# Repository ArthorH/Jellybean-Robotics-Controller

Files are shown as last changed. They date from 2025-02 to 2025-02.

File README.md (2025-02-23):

# ESP8266 Multipurpose robotics controller 
 made from certified jellybean components!
 
obraz

obraz

## Project Status: **Finished**  
**Design** ✅ — **Fabrication** ✅ — **Assembly** ✅ — **Bringup** ✅ — **Testing** ✅  

## Key technologies:
&nbsp;&nbsp;&nbsp;&nbsp; &nbsp;&nbsp;&nbsp;&nbsp; &nbsp;&nbsp;&nbsp;&nbsp; &nbsp;&nbsp;&nbsp;&nbsp;

## Features
- Jelly Bean Components
- Universal footprints
- All usefull gpios has been broken out to connectors
- Additional I2C expander
- Battery voltage measurement
- Integrated easy to solder BMS module footprint (HW341)

Boards in different configuration
## Jelly Bean components 
Board designed to allow manufacture of simple but capable wifi enabled robotics controller from most common avaliable components.



## Universal footprints
Board is designed to handle multiple packages of same components:

 

## Integrated BMS controller 
Integrated easy to solder BMS module footprint (HW341)



## Notice: BMS it needs to be bodged in order to work
This model of bms would not be used in future designs



# Use cases
## PCB mounted on simple mobile robot

## PCB used in a pneumatic controller during the robotic arena.
obraz

## License

MIT

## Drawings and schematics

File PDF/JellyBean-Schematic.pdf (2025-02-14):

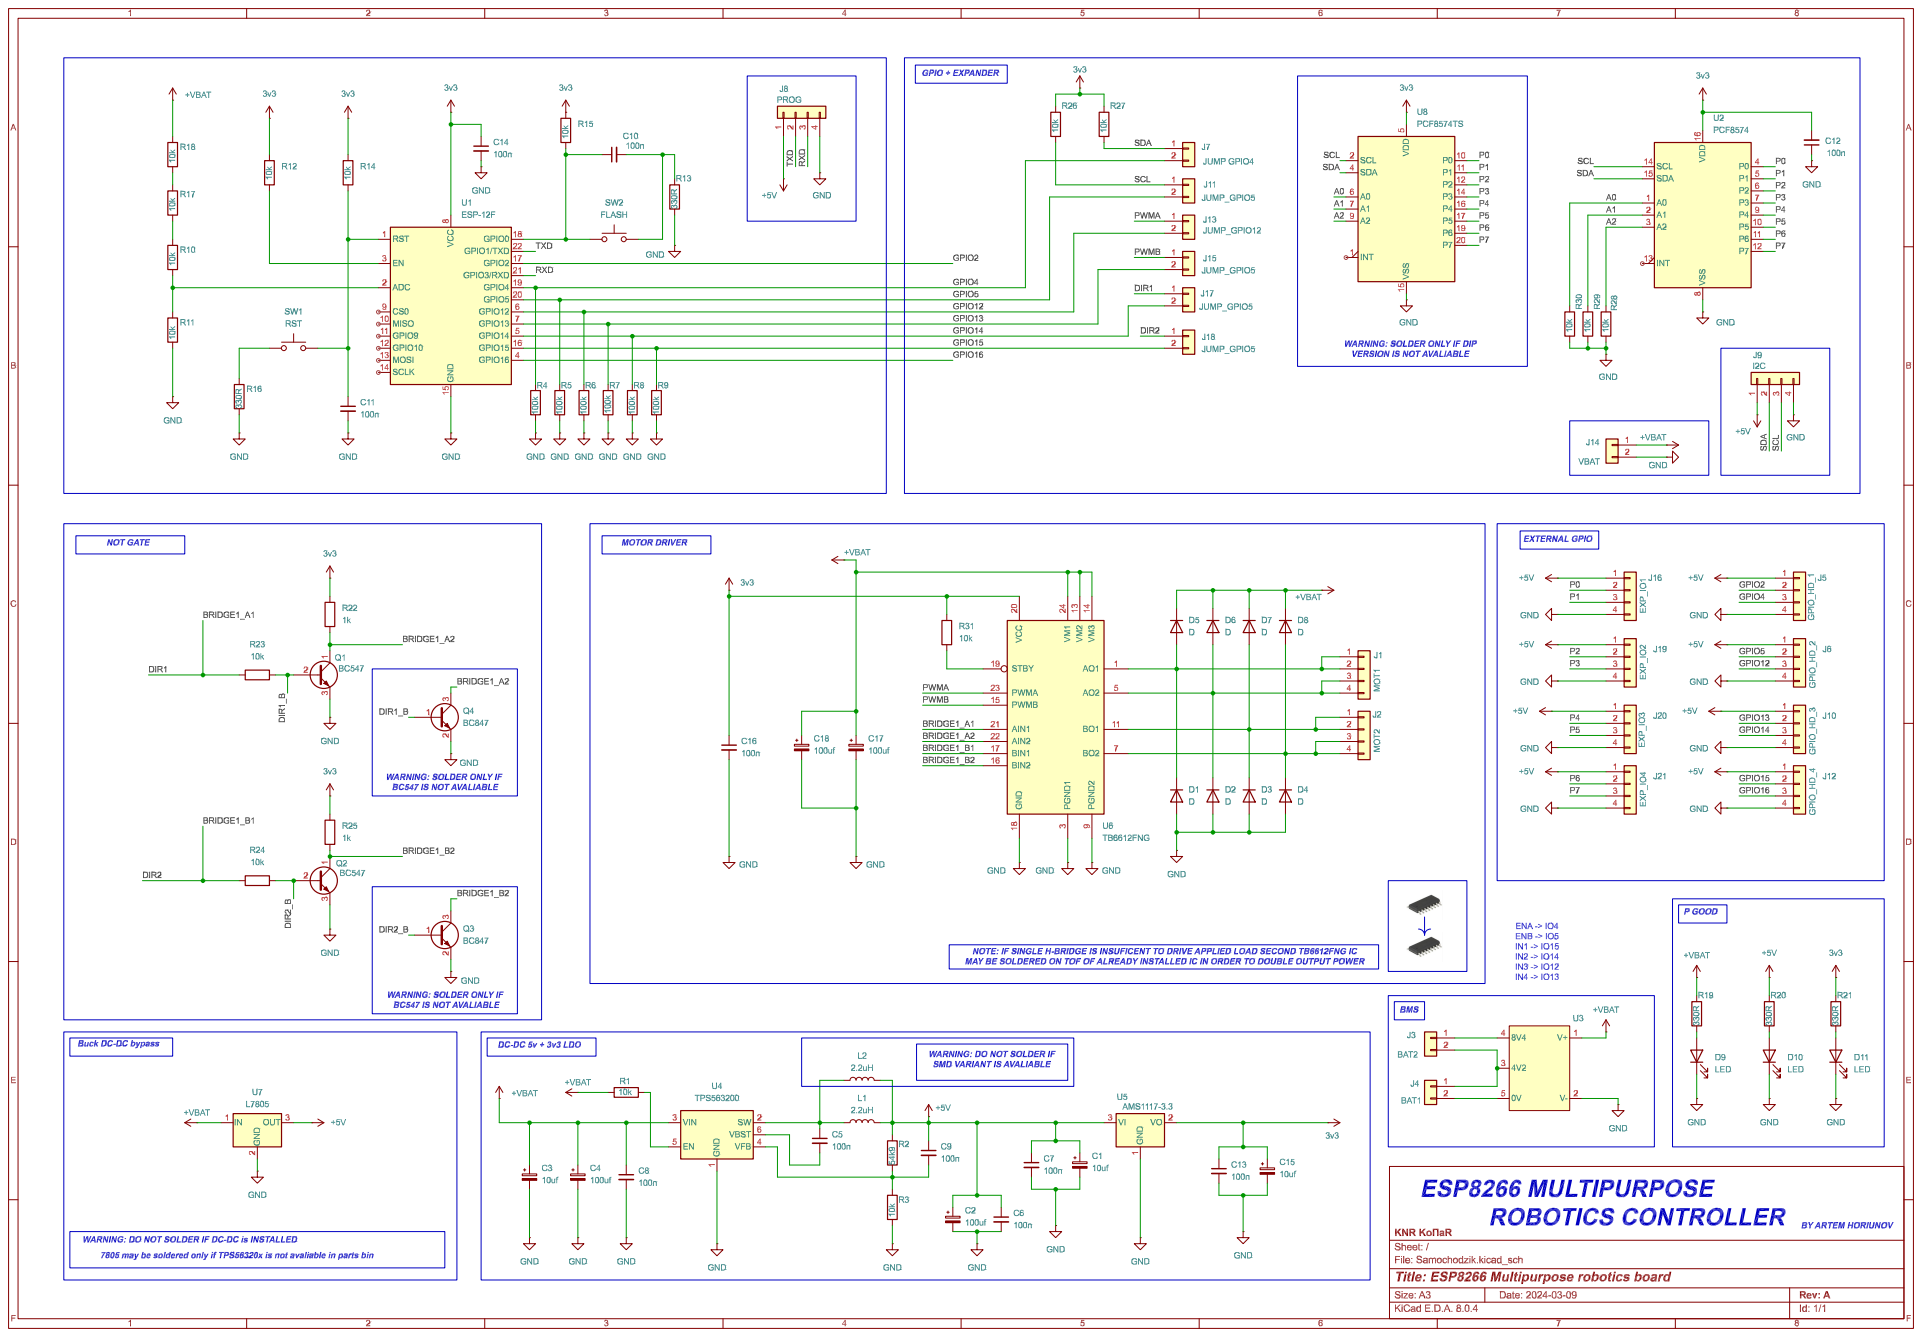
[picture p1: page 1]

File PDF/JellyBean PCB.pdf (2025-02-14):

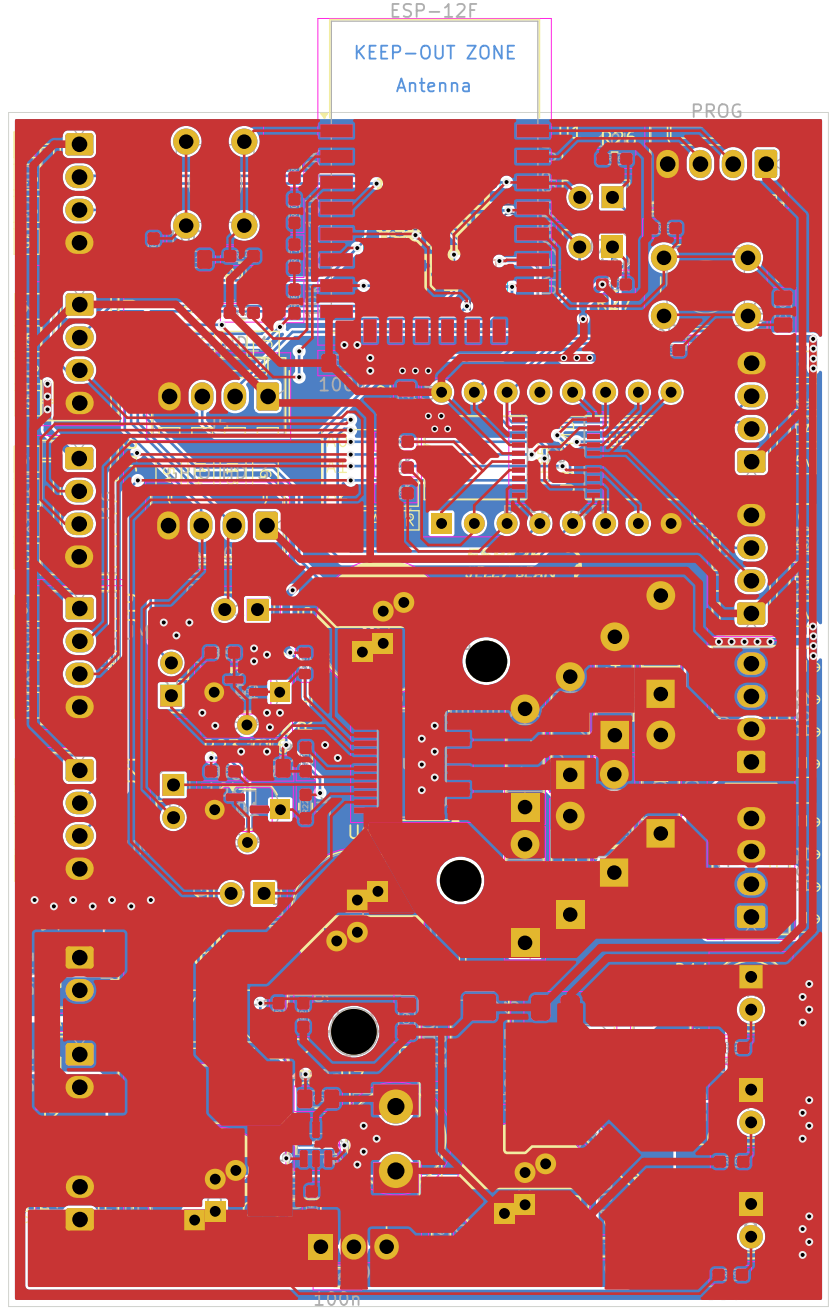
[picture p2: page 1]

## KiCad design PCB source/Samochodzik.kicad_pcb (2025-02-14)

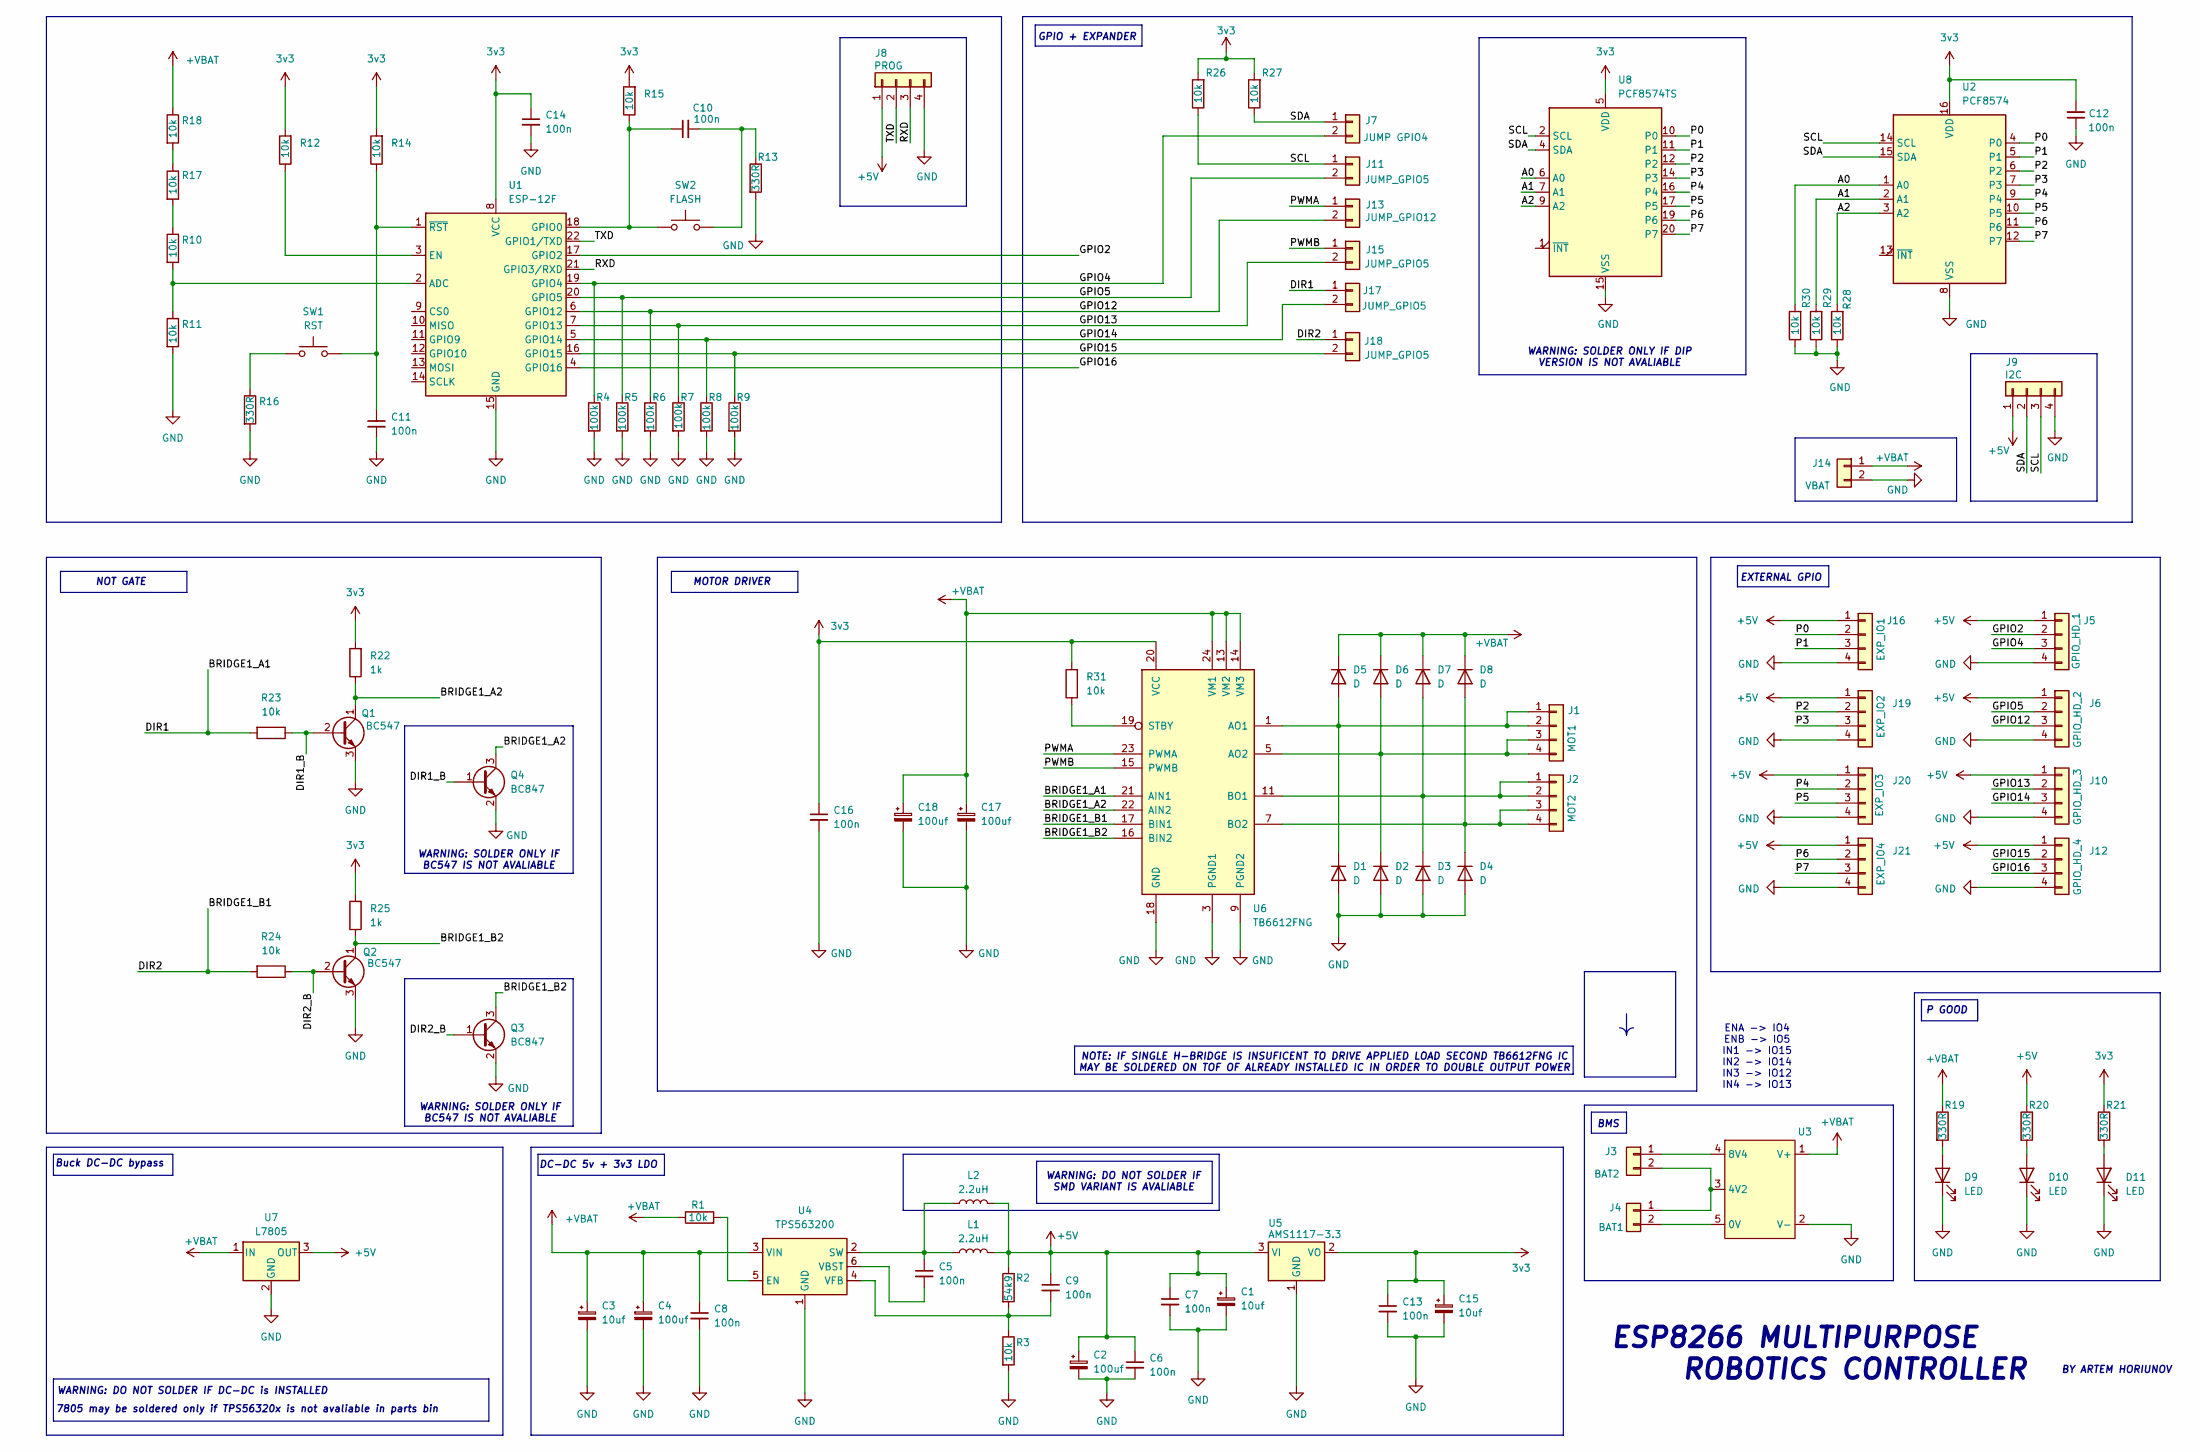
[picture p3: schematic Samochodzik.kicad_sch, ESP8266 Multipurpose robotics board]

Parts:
C1, C3, C15: 10uf; CP_EIA-7343-31_Kemet-D
C2, C4, C17, C18: 100uf; CP_Radial_D10.0mm_P2.50mm_P5.00mm
C5, C6, C7, C8, C9, C10, C11, C12, C13, C14, C16: 100n; C_0805_2012Metric_Pad1.18x1.45mm_HandSolder
D1, D2, D3, D4, D5, D6, D7, D8: D; D_DO-41_SOD81_P7.62mm_Horizontal
D9, D10, D11: LED; LED_D5.0mm
J1: MOT1; Molex_KK-254_AE-6410-04A_1x04_P2.54mm_Vertical
J2: MOT2; Molex_KK-254_AE-6410-04A_1x04_P2.54mm_Vertical
J3: BAT2; Molex_KK-254_AE-6410-02A_1x02_P2.54mm_Vertical
J4: BAT1; Molex_KK-254_AE-6410-02A_1x02_P2.54mm_Vertical
J5: GPIO_HD_1; Molex_KK-254_AE-6410-04A_1x04_P2.54mm_Vertical
J6: GPIO_HD_2; Molex_KK-254_AE-6410-04A_1x04_P2.54mm_Vertical
J7: JUMP GPIO4; PinHeader_1x02_P2.54mm_Vertical
J8: PROG; Molex_KK-254_AE-6410-04A_1x04_P2.54mm_Vertical
J9: I2C; Molex_KK-254_AE-6410-04A_1x04_P2.54mm_Vertical
J10: GPIO_HD_3; Molex_KK-254_AE-6410-04A_1x04_P2.54mm_Vertical
J11, J15, J17, J18: JUMP_GPIO5; PinHeader_1x02_P2.54mm_Vertical
J12: GPIO_HD_4; Molex_KK-254_AE-6410-04A_1x04_P2.54mm_Vertical
J13: JUMP_GPIO12; PinHeader_1x02_P2.54mm_Vertical
J14: VBAT; Molex_KK-254_AE-6410-02A_1x02_P2.54mm_Vertical
J16: EXP_IO1; Molex_KK-254_AE-6410-04A_1x04_P2.54mm_Vertical
J19: EXP_IO2; Molex_KK-254_AE-6410-04A_1x04_P2.54mm_Vertical
J20: EXP_IO3; Molex_KK-254_AE-6410-04A_1x04_P2.54mm_Vertical
J21: EXP_IO4; Molex_KK-254_AE-6410-04A_1x04_P2.54mm_Vertical
L1: 2.2uH; L_Sunlord_MWSA0624S
L2: 2.2uH; L_Radial_D7.5mm_P5.00mm_Fastron_07P
Q1, Q2: BC547; TO-92_Wide
Q3, Q4: BC847; SOT-23
R1, R3, R10, R11, R12, R14, R15, R17, R18, R23, R24, R26, R27, R28, R29, R30, R31: 10k; R_0603_1608Metric_Pad0.98x0.95mm_HandSolder
R2: 54k9; R_0603_1608Metric_Pad0.98x0.95mm_HandSolder
R4, R5, R6, R7, R8, R9: 100k; R_0603_1608Metric_Pad0.98x0.95mm_HandSolder
R13, R16, R19, R20, R21: 330R; R_0603_1608Metric_Pad0.98x0.95mm_HandSolder
R22: 1k; R_0603_1608Metric_Pad0.98x0.95mm_HandSolder
R25: 1k; R_0603_1608Metric
SW1: RST; SW_PUSH_6mm_H4.3mm
SW2: FLASH; SW_PUSH_6mm_H4.3mm
U1: ESP-12F; ESP-12E
U2: PCF8574; DIP-16_W10.16mm
U3: Chinese 20A BMS
U4: TPS563200; SOT-23-6
U5: AMS1117-3.3; SOT-223-3_TabPin2
U6: TB6612FNG; SSOP-24_5.3x8.2mm_P0.65mm
U7: L7805; TO-220-3_Horizontal_TabDown
U8: PCF8574TS; SSOP-20_4.4x6.5mm_P0.65mm

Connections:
3v3: C12.2, C13.1, C14.1, C15.1, C16.1, R12.2, R14.2, R15.2, R21.1, R22.2, R25.2, R26.2, R27.2, R31.2, U1.8 (VCC), U2.16 (VDD), U5.2 (VO), U6.20 (VCC), U8.5 (VDD)
+5V: C1.1, C2.1, C6.1, C7.1, C9.1, J5.1, J6.1, J8.1, J9.1, J10.1, J12.1, J16.1, J19.1, J20.1, J21.1, L1.2, L2.2, R2.1, R20.1, U5.3 (VI), U7.3 (OUT)
+VBAT: C3.1, C4.1, C8.1, C17.1, C18.1, D5.1 (K), D6.1 (K), D7.1 (K), D8.1 (K), J14.1, R1.1, R18.1, R19.1, U3.1 (V+), U4.3 (VIN), U6.13 (VM2), U6.14 (VM3), U6.24 (VM1), U7.1 (IN)
/A0: R30.2, U2.1 (A0), U8.6 (A0)
/A1: R29.2, U2.2 (A1), U8.7 (A1)
/A2: R28.2, U2.3 (A2), U8.9 (A2)
/BRIDGE1_A1: J17.1, R23.2, U6.21 (AIN1)
/BRIDGE1_A2: Q1.1 (C), Q4.3 (C), R22.1, U6.22 (AIN2)
/BRIDGE1_B1: J18.1, R24.2, U6.17 (BIN1)
/BRIDGE1_B2: Q2.1 (C), Q3.3 (C), R25.1, U6.16 (BIN2)
/DIR1_B: Q1.2 (B), Q4.1 (B), R23.1
/DIR2_B: Q2.2 (B), Q3.1 (B), R24.1
/GPIO2: J5.2, U1.17 (GPIO2)
/GPIO4: J5.3, J7.2, R4.1, U1.19 (GPIO4)
/GPIO5: J6.2, J11.2, R5.1, U1.20 (GPIO5)
/GPIO12: J6.3, J13.2, R6.1, U1.6 (GPIO12)
/GPIO13: J10.2, J15.2, R7.1, U1.7 (GPIO13)
/GPIO14: J10.3, J17.2, R8.1, U1.5 (GPIO14)
/GPIO15: J12.2, J18.2, R9.1, U1.16 (GPIO15)
/GPIO16: J12.3, U1.4 (GPIO16)
/P0: J16.2, U2.4 (P0), U8.10 (P0)
/P1: J16.3, U2.5 (P1), U8.11 (P1)
/P2: J19.2, U2.6 (P2), U8.12 (P2)
/P3: J19.3, U2.7 (P3), U8.14 (P3)
/P4: J20.2, U2.9 (P4), U8.16 (P4)
/P5: J20.3, U2.10 (P5), U8.17 (P5)
/P6: J21.2, U2.11 (P6), U8.19 (P6)
/P7: J21.3, U2.12 (P7), U8.20 (P7)
/PWMA: J13.1, U6.23 (PWMA)
/PWMB: J15.1, U6.15 (PWMB)
/RXD: J8.3, U1.21 (GPIO3/RXD)
/SCL: J9.3, J11.1, R26.1, U2.14 (SCL), U8.2 (SCL)
/SDA: J7.1, J9.2, R27.1, U2.15 (SDA), U8.4 (SDA)
/TXD: J8.2, U1.22 (GPIO1/TXD)
GND: C1.2, C2.2, C3.2, C4.2, C6.2, C7.2, C8.2, C11.2, C12.1, C13.2, C14.2, C15.2, C16.2, C17.2, C18.2, D1.2 (A), D2.2 (A), D3.2 (A), D4.2 (A), D9.1 (K), D10.1 (K), D11.1 (K), J5.4, J6.4, J8.4, J9.4, J10.4, J12.4, J14.2, J16.4, J19.4, J20.4, J21.4, Q1.3 (E), Q2.3 (E), Q3.2 (E), Q4.2 (E), R3.2, R4.2, R5.2, R6.2, R7.2, R8.2, R9.2, R11.2, R13.2, R16.2, R28.1, R29.1, R30.1, U1.15 (GND), U2.8 (VSS), U3.2 (V-), U4.1 (GND), U5.1 (GND), U6.3 (PGND1), U6.4 (PGND1), U6.9 (PGND2), U6.10 (PGND2), U6.18 (GND), U7.2 (GND), U8.15 (VSS)
unnamed: C10.2, R13.1, SW2.2
unnamed: D1.1 (K), D5.2 (A), J1.1, J1.2, U6.1 (AO1), U6.2 (AO1)
unnamed: D2.1 (K), D6.2 (A), J1.3, J1.4, U6.5 (AO2), U6.6 (AO2)
unnamed: D3.1 (K), D7.2 (A), J2.1, J2.2, U6.11 (BO1), U6.12 (BO1)
unnamed: D4.1 (K), D8.2 (A), J2.3, J2.4, U6.7 (BO2), U6.8 (BO2)
unnamed: D9.2 (A), R19.2
unnamed: D10.2 (A), R20.2
unnamed: D11.2 (A), R21.2
unnamed: J3.1, U3.4 (8V4)
unnamed: J3.2, J4.1, U3.3 (4V2)
unnamed: J4.2, U3.5 (0V)
unnamed: R10.1, R17.2
unnamed: R16.1, SW1.1
unnamed: R17.1, R18.2
unnamed: R10.2, R11.1, U1.2 (ADC)
unnamed: R12.1, U1.3 (EN)
unnamed: C10.1, R15.1, SW2.1, U1.18 (GPIO0)
unnamed: C11.1, R14.1, SW1.2, U1.1 (~RST)
unnamed: R1.2, U4.5 (EN)
unnamed: C5.1, L1.1, L2.1, U4.2 (SW)
unnamed: C5.2, U4.6 (VBST)
unnamed: C9.2, R2.2, R3.1, U4.4 (VFB)
unnamed: R31.1, U6.19 (STBY)

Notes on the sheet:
BY ARTEM HORIUNOV
BMS
NOT GATE
WARNING: SOLDER ONLY IF BC547 IS NOT AVALIABLE
WARNING: DO NOT SOLDER IF SMD VARIANT IS AVALIABLE
WARNING: DO NOT SOLDER IF DC-DC is INSTALLED
ESP8266 MULTIPURPOSE ROBOTICS CONTROLLER
P GOOD
MOTOR DRIVER
NOTE: IF SINGLE H-BRIDGE IS INSUFICENT TO DRIVE APPLIED LOAD SECOND TB6612FNG IC MAY BE SOLDERED ON TOF OF ALREADY INSTALLED IC IN ORDER TO DOUBLE OUTPUT POWER
Buck DC-DC bypass
GPIO + EXPANDER
ENA -> IO4 ENB -> IO5 IN1 -> IO15 IN2 -> IO14 IN3 -> IO12 IN4 -> IO13
DC-DC 5v + 3v3 LDO
WARNING: SOLDER ONLY IF DIP VERSION IS NOT AVALIABLE
7805 may be soldered only if TPS56320x is not avaliable in parts bin
EXTERNAL GPIO

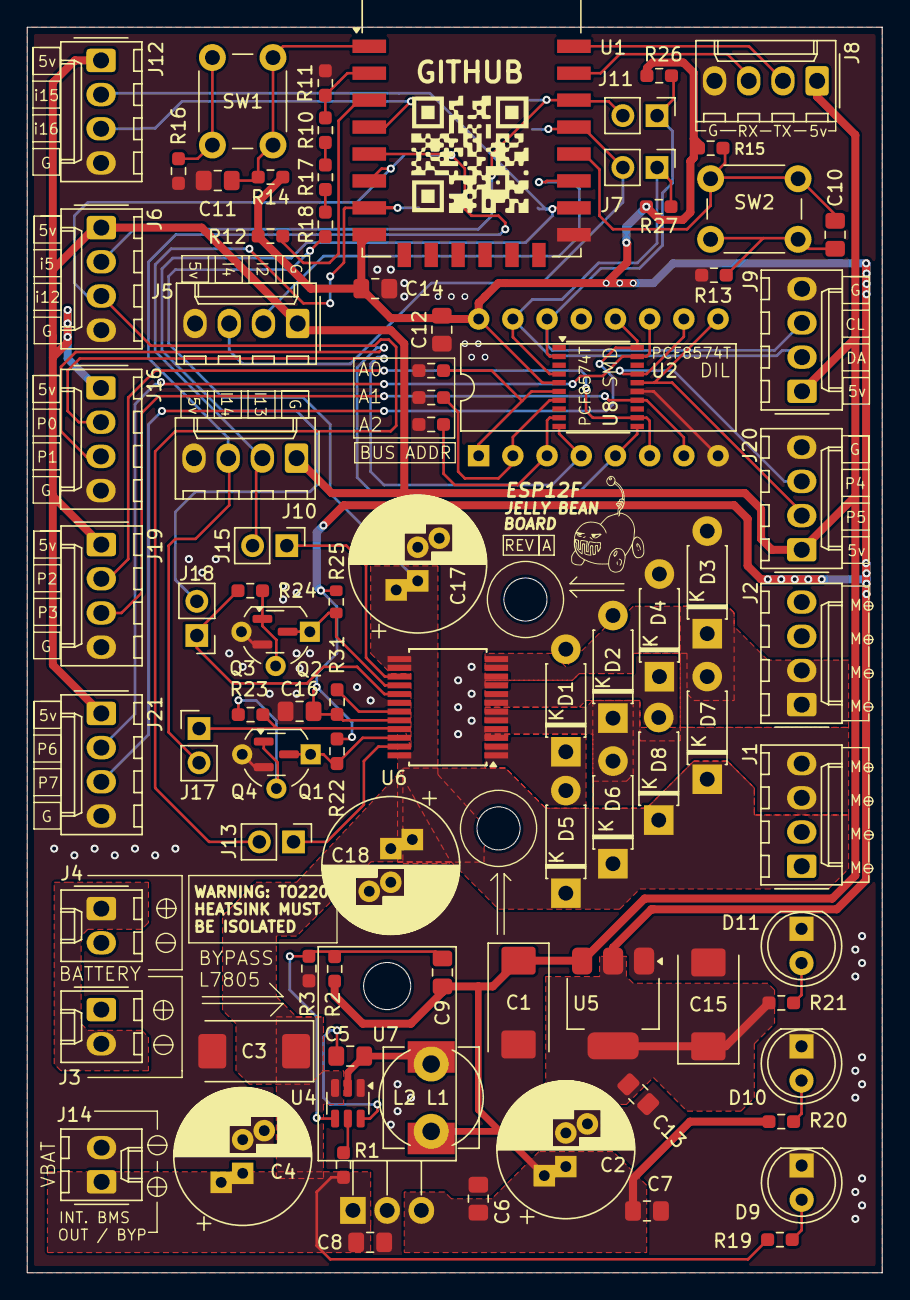
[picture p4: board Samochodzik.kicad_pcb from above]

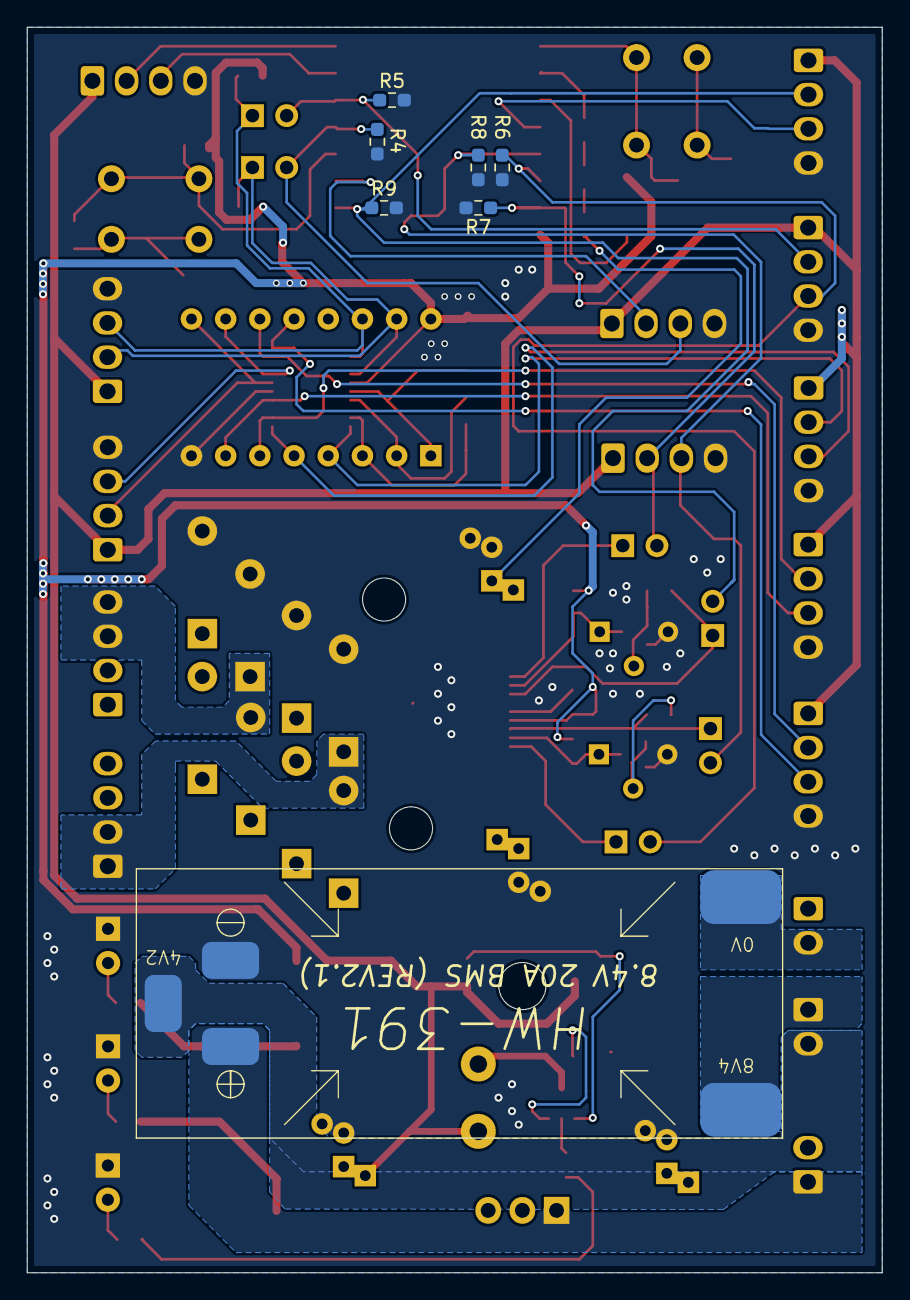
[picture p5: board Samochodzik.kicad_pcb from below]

Board: 2 copper layers, 63.5 x 92.5 mm, 99 parts (7 on the bottom side), 58 nets.

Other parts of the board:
H1, H2: MountingHole; MountingHole_3.2mm_M3_DIN965

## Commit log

2024-03-12 DRC errors corrected
    [Samochodzik-B_Cu.gbl, Samochodzik-B_Mask.gbs, Samochodzik-B_Paste.gbp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]
2024-03-13 Update BOM in ReadMe.md
2025-02-14 Do cleanup
    [Samochodzik-B_Cu.gbl, Samochodzik-B_Mask.gbs, Samochodzik-B_Paste.gbp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]
